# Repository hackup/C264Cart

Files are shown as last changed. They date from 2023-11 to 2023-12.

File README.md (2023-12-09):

# C264Cart

The C264Cart ist a modernized ROM cartridge for the Commodore 264 family of 8-bit computers, the Commodore C16, C116, and Plus/4.

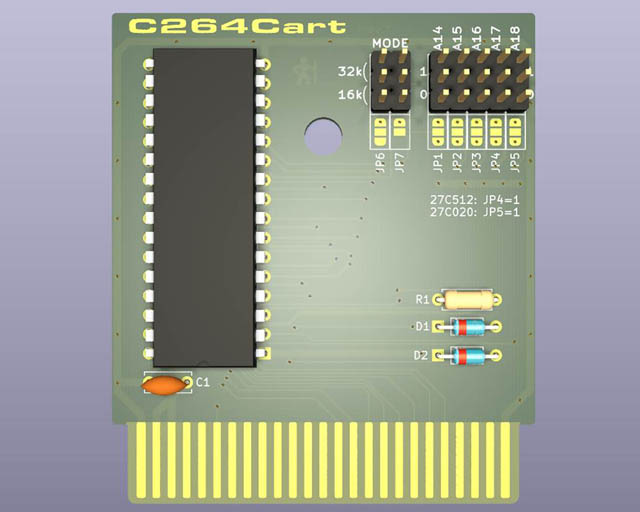
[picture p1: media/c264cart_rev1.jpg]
C264Cart Rev.1


I started out by first reverse engineering and replicating the layout of an original ROM cartridge. Then I adapted it to better suit EPROMS and EEPROMS that are still readily  available today, such as the W27C512 and W27C020.  The layout was also scaled down to save shipping costs, but still fits the original cartridge shells.

See my [blog post](https://www.hackup.net/2023/12/making-cartridges-for-the-commodore-c16-c116-and-plus-4/) for more details.

I also created a simplified version of the original cartridge case for 3D printing that works well with the C264Cart. It is currently available for personal use on [Thingiverse](https://www.thingiverse.com/thing:6309306) and [Printables](https://www.printables.com/model/644139-commodore-264-cartridge-case-redux-for-c16-and-plu).

## Configuration Options

There are two things that need to be configured, the type of EPROM to be used and the size of the targeted ROM images. 

The C264Cart can be configured to support either 16k ROM images or 32k ROM images by setting JP6 and JP7 accordingly. 32k ROM images for the 264 computers usually consist of two 16k parts that were originally stored in two separate ROMs. On the C264Cart in 32k mode, both parts go into the same EPROM with the upper part directly following the lower one. As a result, A14 cannot be used for external bank switching in 32k mode. It is automatically selected by the cartridge.

If the C264Cart is configured for 16k mode R1, D1, and D2 don't need to be populated. These components are used in 32k mode, only.

The C264Cart supports 27C512, 27C020, and 27C040 (E)EPROMs. Make sure that these ICs are always aligned to the top of the cartridge as indicated on the silkscreen and that the jumpers JP4 and JP5 are set correctly!

### 27C512 for 4 ROM images with 16k each

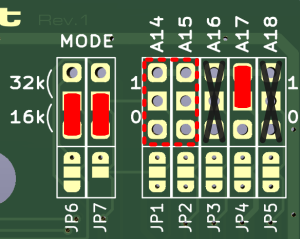
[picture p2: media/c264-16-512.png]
27C512-16k


| Address | | A14 | A15 |
|---:|---|:---:|:---:|
| 0x0000 | ROM 1 |  0  |  0  |
| 0x4000 | ROM 2 |  1  |  0  |
| 0x8000 | ROM 3 |  0  |  1  |
| 0xC000 | ROM 4 |  1  |  1  |

### 27C020 for 16 ROM images with 16k each

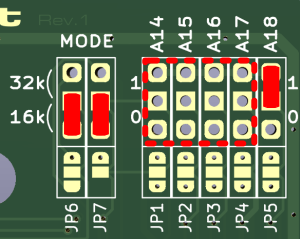
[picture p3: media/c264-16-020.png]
27C020-16k


| Address | | A14 | A15 | A16 | A17 |
|---:|---|:---:|:---:|:---:|:---:|
| 0x00000 | ROM 1 |  0  |  0  |  0  |  0  |
| 0x04000 | ROM 2 |  1  |  0  |  0  |  0  |
| 0x08000 | ROM 3 |  0  |  1  |  0  |  0  |
| 0x0C000 | ROM 4 |  1  |  1  |  0  |  0  |
| 0x10000 | ROM 5 |  0  |  0  |  1  |  0  |
| ... | ... | ... | ... | ... | ... |
| 0x3C000 | ROM 16 |  1  |  1  |  1  |  1  |

### 27C040 for 32 ROM images with 16k each

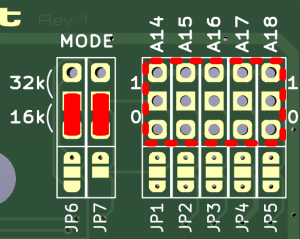
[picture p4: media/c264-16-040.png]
27C040-16k


| Address | | A14 | A15 | A16 | A17 | A18 |
|---:|---|:---:|:---:|:---:|:---:|:---:|
| 0x00000 | ROM 1 |  0  |  0  |  0  |  0  |  0  |
| 0x04000 | ROM 2 |  1  |  0  |  0  |  0  |  0  |
| 0x08000 | ROM 3 |  0  |  1  |  0  |  0  |  0  |
| 0x0C000 | ROM 4 |  1  |  1  |  0  |  0  |  0  |
| 0x10000 | ROM 5 |  0  |  0  |  1  |  0  |  0  |
| ... | ... | ... | ... | ... | ... | ... |
| 0x7C000 | ROM 32 |  1  |  1  |  1  |  1  |  1  |

### 27C512 for 2 ROM images with 32k each
A14 must be left open!

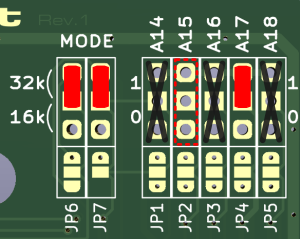
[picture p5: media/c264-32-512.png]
27C512-32k


| Address | | A14 | A15 |
|---:|---|:---:|:---:|
| 0x0000 | ROM 1 low |  x  |  0  |
| 0x4000 | ROM 1 high  |  x  | |
| 0x8000 | ROM 2 low |  x  |  1  |
| 0xC000 | ROM 2 high  |  x  | |

### 27C020 for 8 ROM images with 32k each
A14 must be left open!

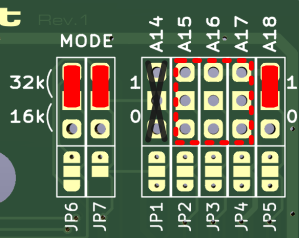
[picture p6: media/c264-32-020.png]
27C020-32k


| Address | | A14 | A15 | A16 | A17 |
|---:|---|:---:|:---:|:---:|:---:|
| 0x00000 | ROM 1 low |  x  |  0  |  0  |  0  |
| 0x04000 | ROM 1 high  |  x  | | | |
| 0x08000 | ROM 2 low |  x  |  1  |  0  |  0  |
| 0x0C000 | ROM 2 high  |  x  | | | |
| ... | ... |  x  | ... | ... | ... |
| 0x38000 | ROM 8 low |  x  |  1  |  1  |  1  |
| 0x3C000 | ROM 8 high  |  x  | | | |

### 27C040 for 16 ROM images with 32k each
A14 must be left open!

27C020-32k

| Address | | A14 | A15 | A16 | A17 | A18 |
|---:|---|:---:|:---:|:---:|:---:|:---:|
| 0x00000 | ROM 1 low |  x  |  0  |  0  |  0  |  0  |
| 0x04000 | ROM 1 high  |  x  | | | | |
| 0x08000 | ROM 2 low |  x  |  1  |  0  |  0  |  0  |
| 0x0C000 | ROM 2 high  |  x  | | | | |
| ... | ... |  x  | ... | ... | ... | ... |
| 0x78000 | ROM 16 low  |  x  |  1  |  1  |  1  |  1  |
| 0x7C000 | ROM 16 high |  x  | | | | |

### Caption

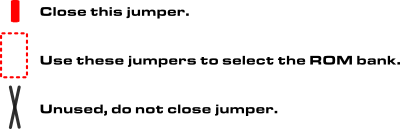
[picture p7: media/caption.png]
Caption


## License

 **USE AT YOUR OWN RISK!**.



This work is licensed under a
[Creative Commons Attribution-NonCommercial-ShareAlike 4.0 International License](http://creativecommons.org/licenses/by-nc-sa/4.0/).

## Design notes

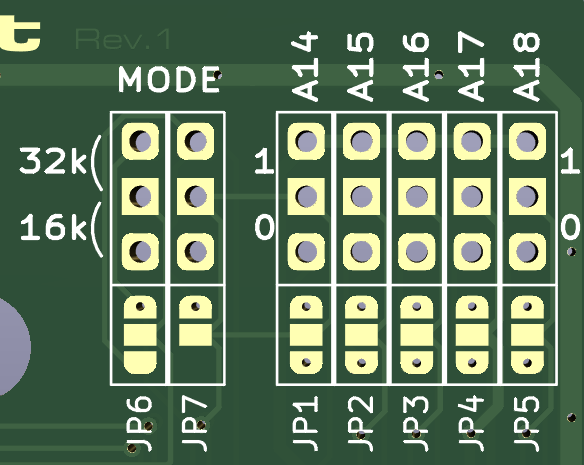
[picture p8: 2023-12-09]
media/c264cart_jumpers.png

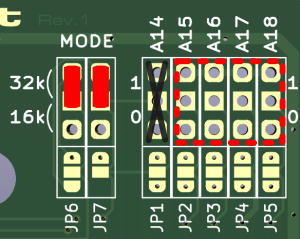
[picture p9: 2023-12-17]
media/c264-32-040.png

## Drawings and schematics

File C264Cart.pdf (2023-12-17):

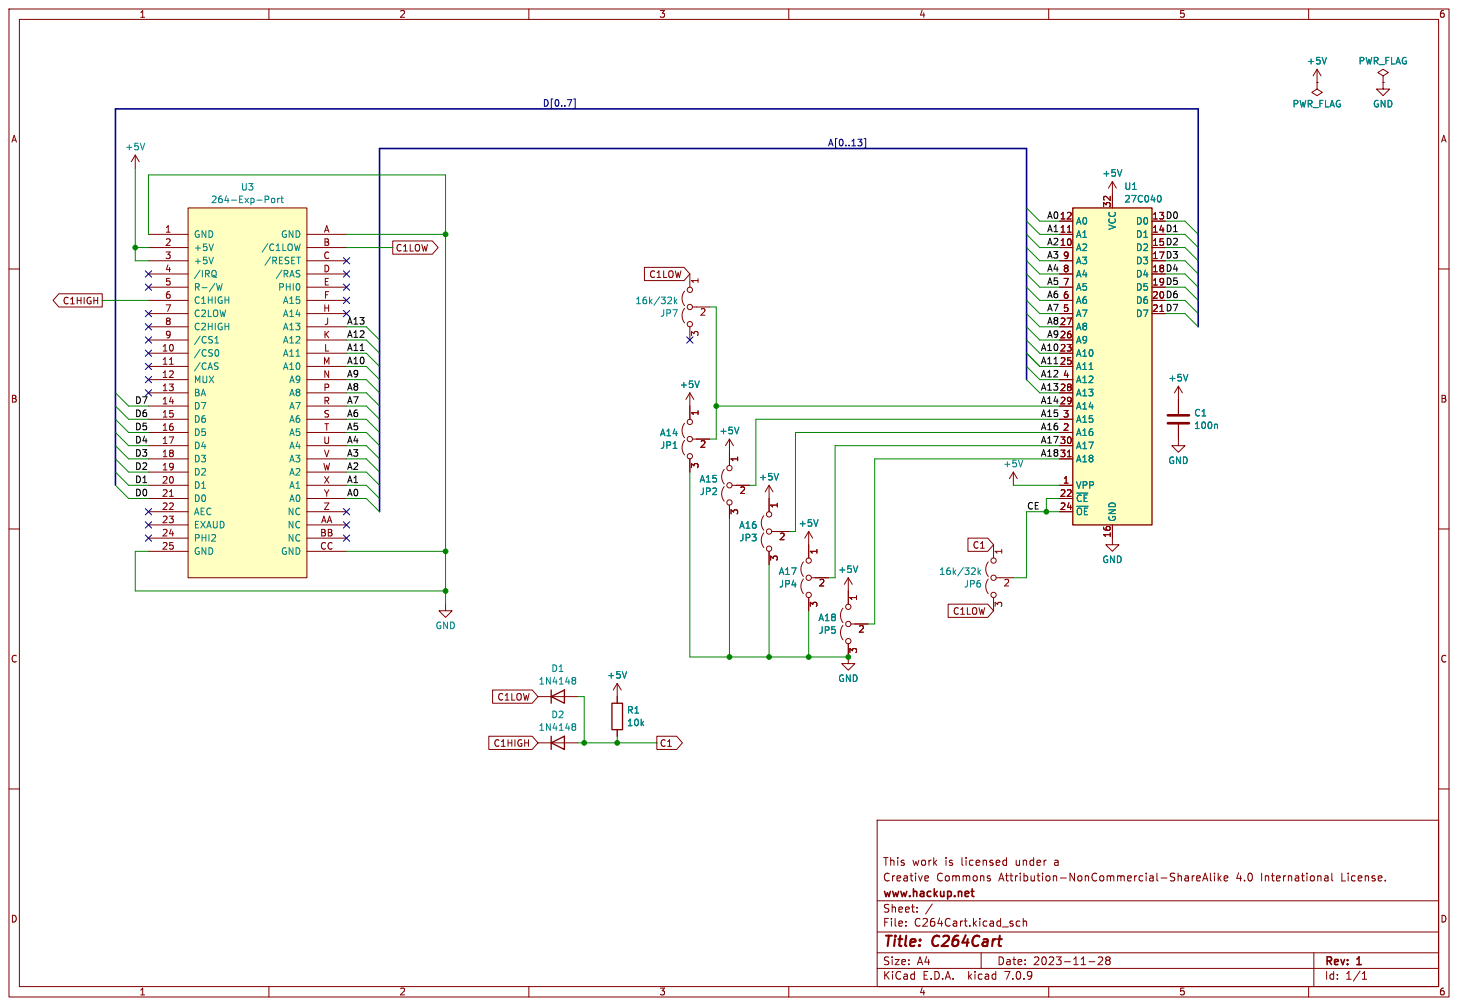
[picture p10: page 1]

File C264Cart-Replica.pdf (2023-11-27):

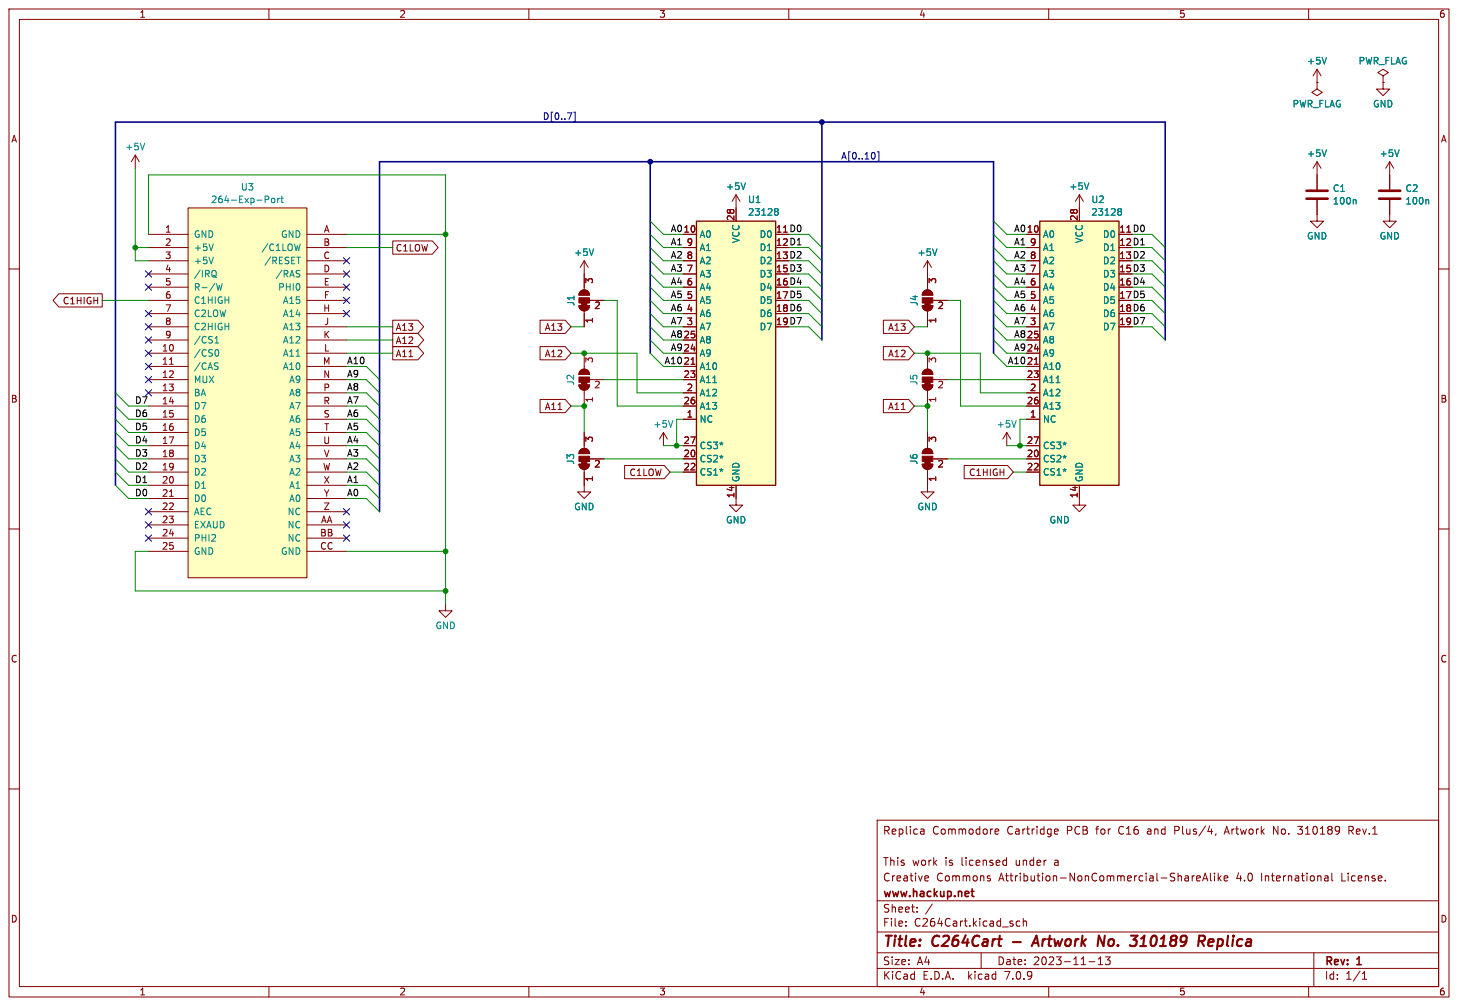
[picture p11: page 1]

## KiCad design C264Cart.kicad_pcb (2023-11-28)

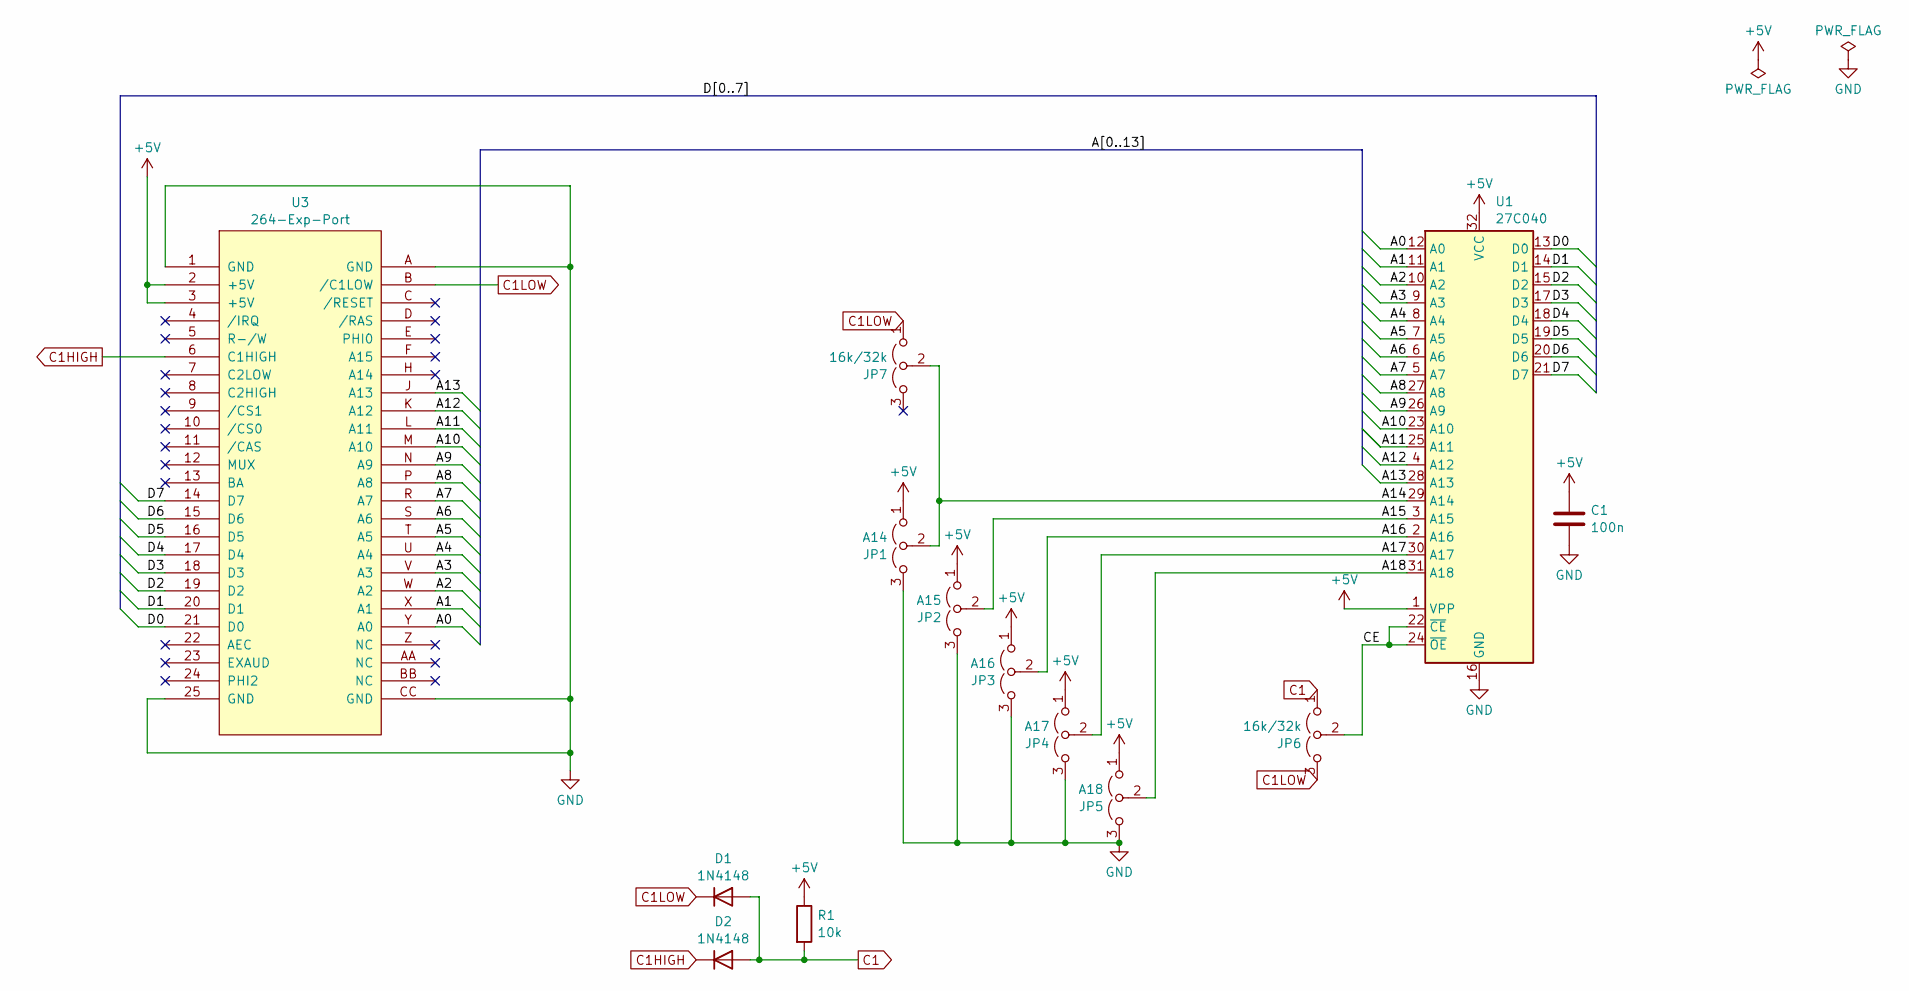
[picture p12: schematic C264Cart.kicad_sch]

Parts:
C1: 100n; C_Disc_D6.0mm_W2.5mm_P5.00mm
D1, D2: 1N4148; D_DO-35_SOD27_P7.62mm_Horizontal
JP1: A14; Jumper3_Solder
JP2: A15; Jumper3_Solder
JP3: A16; Jumper3_Solder
JP4: A17; Jumper3_Solder
JP5: A18; Jumper3_Solder
JP6, JP7: 16k/32k; Jumper3_Solder
R1: 10k; R_Axial_DIN0207_L6.3mm_D2.5mm_P7.62mm_Horizontal
U1: 27C040; DIP-28-32_W15.24mm
U3: 264-Exp-Port; C264-Cart-NoSilkS

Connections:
+5V: C1.1, JP1.1 (A), JP2.1 (A), JP3.1 (A), JP4.1 (A), JP5.1 (A), R1.1, U1.1 (VPP), U1.32 (VCC), U3.2 (+5V), U3.3 (+5V)
/A0: U1.12 (A0), U3.Y (A0)
/A1: U1.11 (A1), U3.X (A1)
/A2: U1.10 (A2), U3.W (A2)
/A3: U1.9 (A3), U3.V (A3)
/A4: U1.8 (A4), U3.U (A4)
/A5: U1.7 (A5), U3.T (A5)
/A6: U1.6 (A6), U3.S (A6)
/A7: U1.5 (A7), U3.R (A7)
/A8: U1.27 (A8), U3.P (A8)
/A9: U1.26 (A9), U3.N (A9)
/A10: U1.23 (A10), U3.M (A10)
/A11: U1.25 (A11), U3.L (A11)
/A12: U1.4 (A12), U3.K (A12)
/A13: U1.28 (A13), U3.J (A13)
/A14: JP1.2 (C), JP7.2 (C), U1.29 (A14)
/A15: JP2.2 (C), U1.3 (A15)
/A16: JP3.2 (C), U1.2 (A16)
/A17: JP4.2 (C), U1.30 (A17)
/A18: JP5.2 (C), U1.31 (A18)
/CE: JP6.2 (C), U1.22 (~CE), U1.24 (~OE)
/D0: U1.13 (D0), U3.21 (D0)
/D1: U1.14 (D1), U3.20 (D1)
/D2: U1.15 (D2), U3.19 (D2)
/D3: U1.17 (D3), U3.18 (D3)
/D4: U1.18 (D4), U3.17 (D4)
/D5: U1.19 (D5), U3.16 (D5)
/D6: U1.20 (D6), U3.15 (D6)
/D7: U1.21 (D7), U3.14 (D7)
C1: D1.2 (A), D2.2 (A), JP6.1 (A), R1.2
C1HIGH: D2.1 (K), U3.6 (C1HIGH)
C1LOW: D1.1 (K), JP6.3 (B), JP7.1 (A), U3.B (/C1LOW)
GND: C1.2, JP1.3 (B), JP2.3 (B), JP3.3 (B), JP4.3 (B), JP5.3 (B), U1.16 (GND), U3.1 (GND), U3.25 (GND), U3.A (GND), U3.CC (GND)

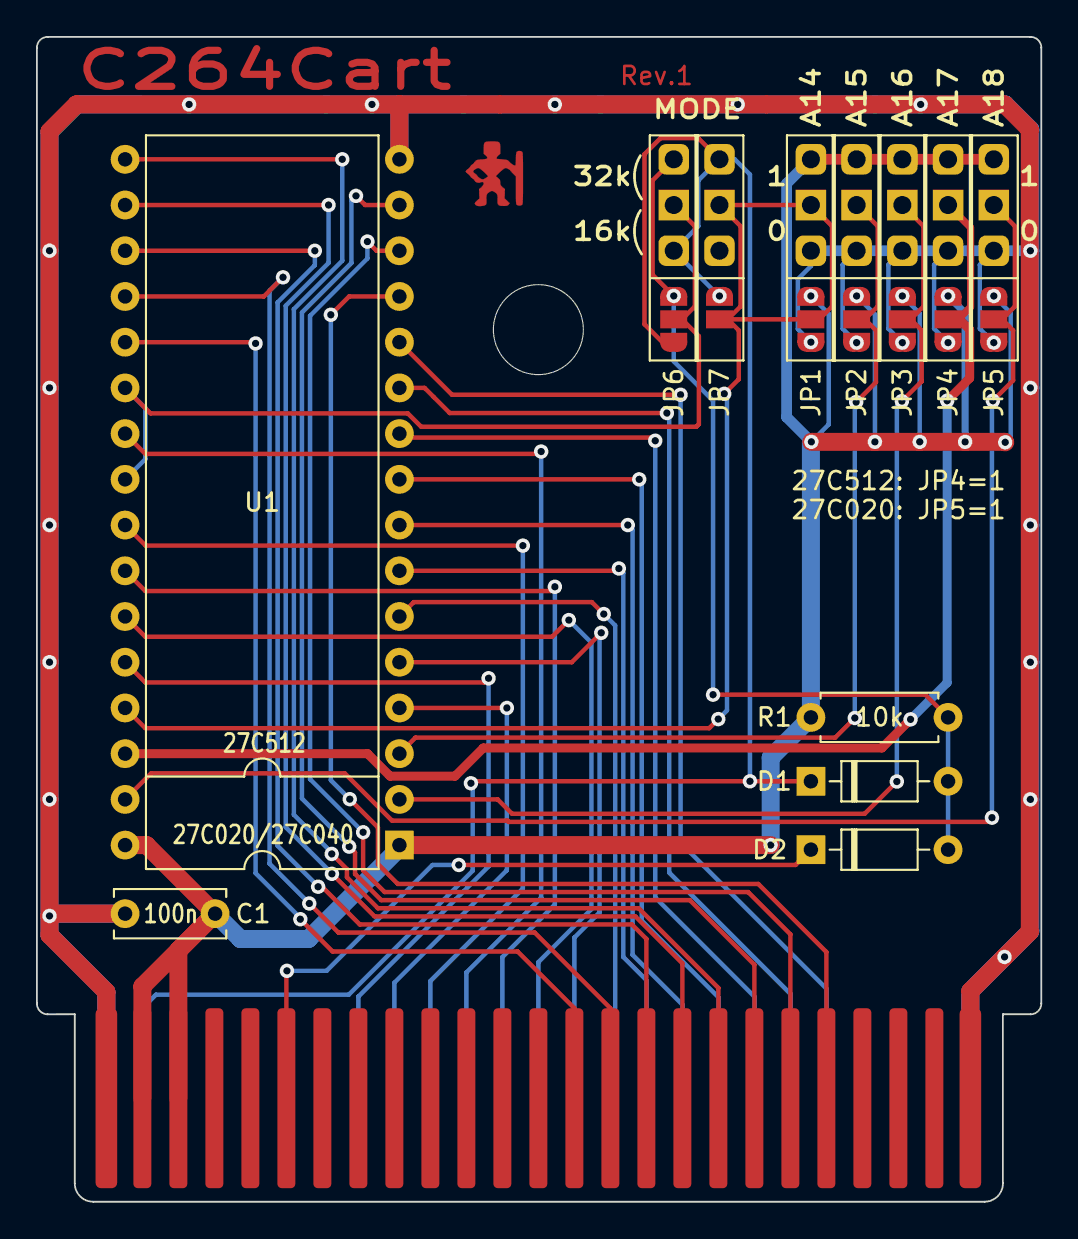
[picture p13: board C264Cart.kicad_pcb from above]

Board: 2 copper layers, 55.8 x 64.7 mm, 13 parts (0 on the bottom side), 33 nets.

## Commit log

2023-11-12 Initial import.
    [C264Cart.kicad_sch]
2023-11-12 Work in progress.
    [C264Cart.kicad_sch]
2023-11-13 Clean up schematics.
    [C264Cart.kicad_sch]
2023-11-13 PCB width.
2023-11-13 Added gerber export dir.
2023-11-13 Preparing for gerber export.
2023-11-14 Working to use a single 'modern' 27C512-27C040 EEPROM.
    [C264Cart.kicad_sch]
2023-11-16 Cart name on solder mask layer.
    [C264Cart.kicad_pcb]
2023-11-27 Added PDF export of schematics from replica branch.
2023-11-28 JLC order number location.
    [C264Cart.kicad_pcb, C264Cart.kicad_sch]
2023-11-28 Fixed bus label.
    [C264Cart.kicad_sch]
2023-11-28 Minor layout fixes.
    [C264Cart.kicad_pcb]
2023-12-17 Add export of current schematics.
